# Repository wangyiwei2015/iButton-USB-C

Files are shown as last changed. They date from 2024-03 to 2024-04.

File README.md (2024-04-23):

# iButton (USB-C)
 [English](README_EN.md)

为配备 USB Type-C 接口的 iOS 设备提供外置的物理按键，可自定义功能。

由 STM32 上的 USB HID middleware 实现，模拟了外置鼠标上的自定义按键。

按键功能在`辅助功能` - `触控` - `辅助触控` 中设置。

Design Preview

## 构建环境

- 主控固件管理和代码生成: **STM32CubeMX**
- 代码编辑器/开发工具: **CLion**
- 编译器: **gcc-arm-none-eabi**
- 烧录工具: **ST-Link Utility** or **STM32CubeProgrammer** or **OpenOCD**

注意：使用 STM32CubeMX 时，可能会要求登录 ST account 。

## 项目文件

- [iButton-FW](iButton-FW1/): 主要固件代码 (CLion/CubeIDE)
- [STM32-iButton](STM32-iButton-v3/): 主板 (立创EDA Pro)
- [EdgeLink](EdgeLink2/): ST-Link V2 to EdgeLink 转接器 (KiCAD)
- [EdgDbg](EdgDbg3/): ST-Link 带有 EdgeLink 连接器 (立创EDA Pro)
- [Case3D](Case3D/): 3D 外壳模型 (Shapr3D)
- [Datasheet](Datasheet/): 参考资料 (PDF)

其中 EdgDbg（Edge-Debugger）的基底是 [开源 ST-Link-V2](https://oshwhub.com/CYIIOT/ST_LINK-V2_1)，将 SWD 相关接口改成 EdgeLink 而成。

## Notes

BOOT0默认下拉到GND；要使STM32启动到下载模式，需要将BOOT0置高。在EdgeLink金手指连接器处，BOOT0直接连接VCC，这样当板卡插入EdgeLink调试器时就会进入下载模式。VCC可选5V或3V3，STM32微控制器的BOOT0是否接受5V输入需要视型号而定。对于STM32L052系列，BOOT0最大输入为VDD+4V，因此可以安全连接。

要烧录和调试STM32-iButton-v3主板，需要使用EdgDbg硬件或EdgeLink+ST-Link（它们是等价的）。

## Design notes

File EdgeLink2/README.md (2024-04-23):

# EdgeLink Adaptor for iButton
连接到 ST-Link V2 调试器上

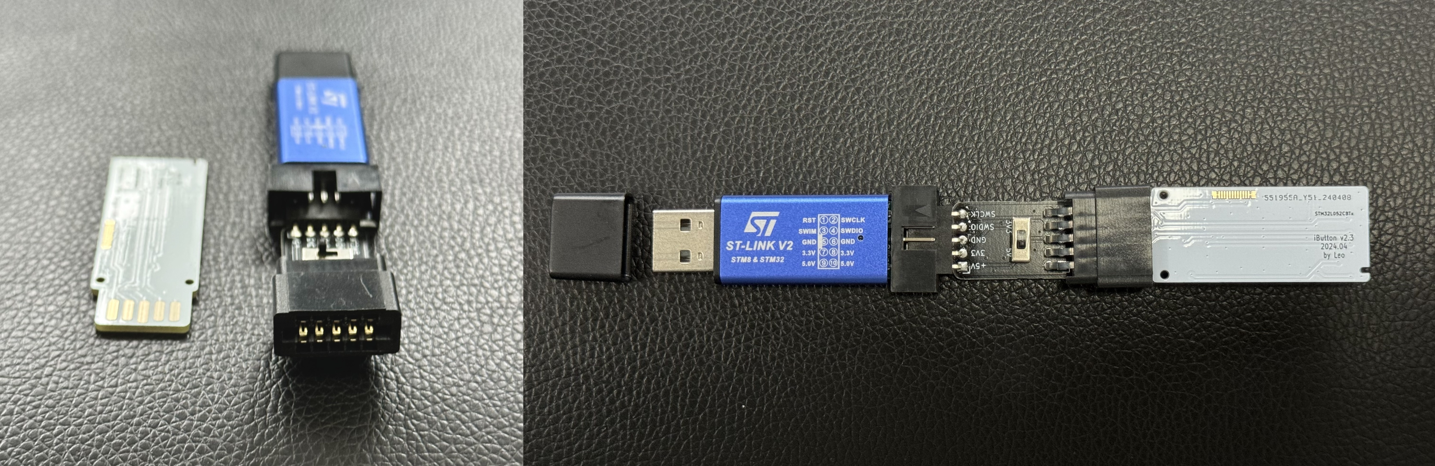
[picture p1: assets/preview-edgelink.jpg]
Design Preview


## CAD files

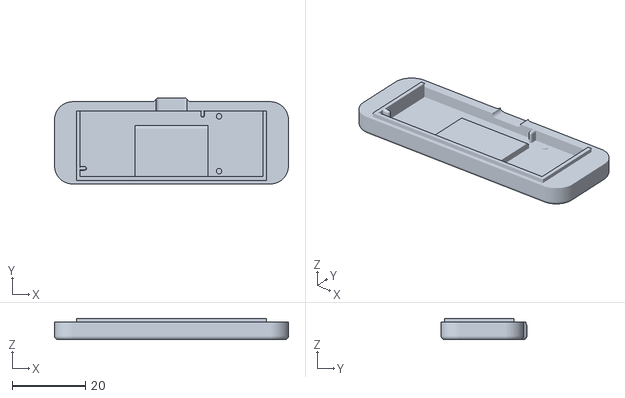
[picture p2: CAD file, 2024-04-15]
Case3D/iButtonCase_Lower_2.1.stl
64.0 x 23.5 x 5.80

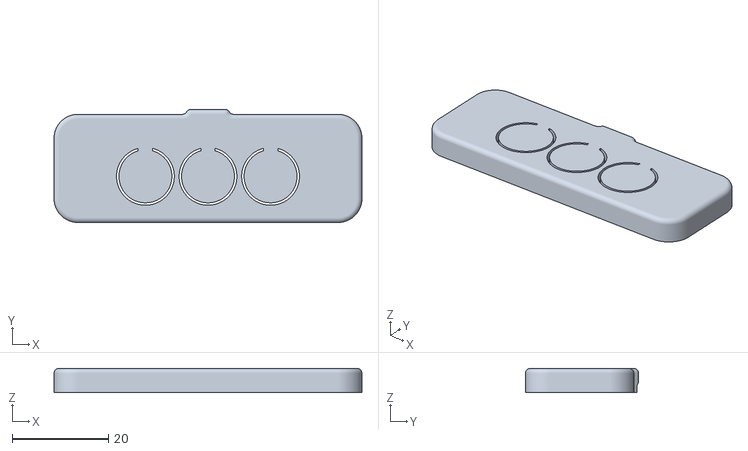
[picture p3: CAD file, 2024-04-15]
Case3D/iButtonCase_Upper_2.1.stl
64.0 x 23.5 x 5.00

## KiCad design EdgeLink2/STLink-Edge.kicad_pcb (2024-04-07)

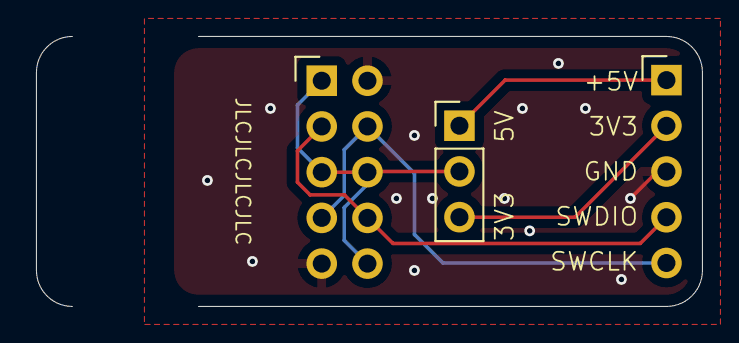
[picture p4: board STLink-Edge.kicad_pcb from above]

Board: 2 copper layers, 37.0 x 15.0 mm, 3 parts (0 on the bottom side), 6 nets.

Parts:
J1: Conn_edge_socket; PinSocket_2x05_P2.54mm_Vertical
J3: Conn_STLink2; PinHeader_1x05_P2.54mm_Vertical
SW1: SW_Push_SPDT; PinHeader_1x03_P2.54mm_Vertical

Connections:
+3.3V: J3.2, SW1.3 (C)
+5V: J3.1, SW1.1 (A)
/Boot: J1.1, J1.3, J1.6, J1.8, SW1.2 (B)
/SWCLK: J1.4, J1.9, J3.5
/SWDIO: J1.2, J1.7, J3.4
GND: J1.5, J1.10, J3.3

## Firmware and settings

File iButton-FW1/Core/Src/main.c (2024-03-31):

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
/* Includes ------------------------------------------------------------------*/
#include "main.h"
#include "usb_device.h"

/* USER CODE BEGIN Includes */
#include "usbd_hid.h"
/* USER CODE END Includes */


void SystemClock_Config(void);
static void MX_GPIO_Init(void);
/**
  * @brief  The application entry point.
  * @retval int
  */
int main(void)
{

  /* MCU Configuration--------------------------------------------------------*/

  /* Reset of all peripherals, Initializes the Flash interface and the Systick. */
  HAL_Init();

  /* Configure the system clock */
  SystemClock_Config();

  /* USER CODE BEGIN SysInit */
  uint8_t buttonReport[5] = {0};
  uint8_t lastButtonReport = 0;
  extern USBD_HandleTypeDef hUsbDeviceFS;
  HAL_Delay(500);
  /* USER CODE END SysInit */

  /* Initialize all configured peripherals */
  MX_GPIO_Init();
  MX_USB_DEVICE_Init();
  /* Infinite loop */
  /* USER CODE BEGIN WHILE */
  while (1)
  {
    if (HAL_GPIO_ReadPin(Btn1_GPIO_Port, Btn1_Pin) == GPIO_PIN_RESET) {
      buttonReport[0] |= 1<<5;
    } else {
      buttonReport[0] &= ~(1<<5);
    }

    if (HAL_GPIO_ReadPin(Btn2_GPIO_Port, Btn2_Pin) == GPIO_PIN_RESET) {
      buttonReport[0] |= 1<<6;
    } else {
      buttonReport[0] &= ~(1<<6);
    }

    if (HAL_GPIO_ReadPin(Btn3_GPIO_Port, Btn3_Pin) == GPIO_PIN_RESET) {
      buttonReport[0] |= 1<<7;
    } else {
      buttonReport[0] &= ~(1<<7);
    }

    if (buttonReport[0] != lastButtonReport) {
      lastButtonReport = buttonReport[0];
      USBD_HID_SendReport(&hUsbDeviceFS, buttonReport, 5);
    }

    HAL_Delay(50);
    /* USER CODE END WHILE */

    /* USER CODE BEGIN 3 */
  }
  /* USER CODE END 3 */
}

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


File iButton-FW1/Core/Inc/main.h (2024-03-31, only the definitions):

#define Btn1_Pin GPIO_PIN_13
#define Btn1_GPIO_Port GPIOC
#define Btn2_Pin GPIO_PIN_14
#define Btn2_GPIO_Port GPIOC
#define Btn3_Pin GPIO_PIN_15
#define Btn3_GPIO_Port GPIOC

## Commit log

2024-03-30 add fab release
    [STM32-iButton.kicad_pcb]
2024-03-31 critical fix: 5V power
    [STLink-Edge-v3.kicad_pcb, STLink-Edge-v3.kicad_sch, STM32-iButton.kicad_pcb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]
2024-03-31 edgelink 2.1
    [STLink-Edge.kicad_pcb, STLink-Edge.kicad_sch]
2024-03-31 critical fix
    [STLink-Edge.kicad_pcb]
2024-03-31 added stlink edge 3
    [STM32-iButton.kicad_pcb]
2024-03-31 init FW1 project
    [stm32l0discovery.cfg]
2024-03-31 added 3D case
    [STM32-iButton.kicad_pcb, iButtonCase_v1.0_Lower.stl, iButtonCase_v1.0_Upper.stl]
2024-04-01 updated silks
    [STM32-iButton.kicad_pcb]
2024-04-07 add front ver
    [STM32-iButton-FrontVer.kicad_pcb]
2024-04-07 gen fab bom pos
    [iBtn2.3-bom.csv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]
2024-04-15 updated model
    [iButtonCase_Lower_2.1.stl, iButtonCase_Lower_v2.stl, iButtonCase_Upper_2.1.stl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]
2024-04-23 removed old project files
    [STM32-iButton-FrontVer.kicad_pcb, STM32-iButton.kicad_pcb, STM32-iButton.kicad_sch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]

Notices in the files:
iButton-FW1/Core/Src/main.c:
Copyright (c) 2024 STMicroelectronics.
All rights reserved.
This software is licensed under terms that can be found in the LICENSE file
